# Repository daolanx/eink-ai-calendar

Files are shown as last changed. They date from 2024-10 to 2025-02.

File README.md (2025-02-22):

# Eink-AI-Calendar

English | [中文版](README-zh.md)

This is an ESP32-based E-ink AI Calendar. Like time itself - which cannot hold onto yesterday, makes each day new, and keeps tomorrow unknown - it displays daily images and text that cannot be saved or changed, with a low-power, switch-free design.

## 1. Features

- Displays date, weather, and holiday information
- Shows daily inspirational quotes
- Displays AI-generated images based on weather, holidays, and quotes
- Automatically updates at midnight

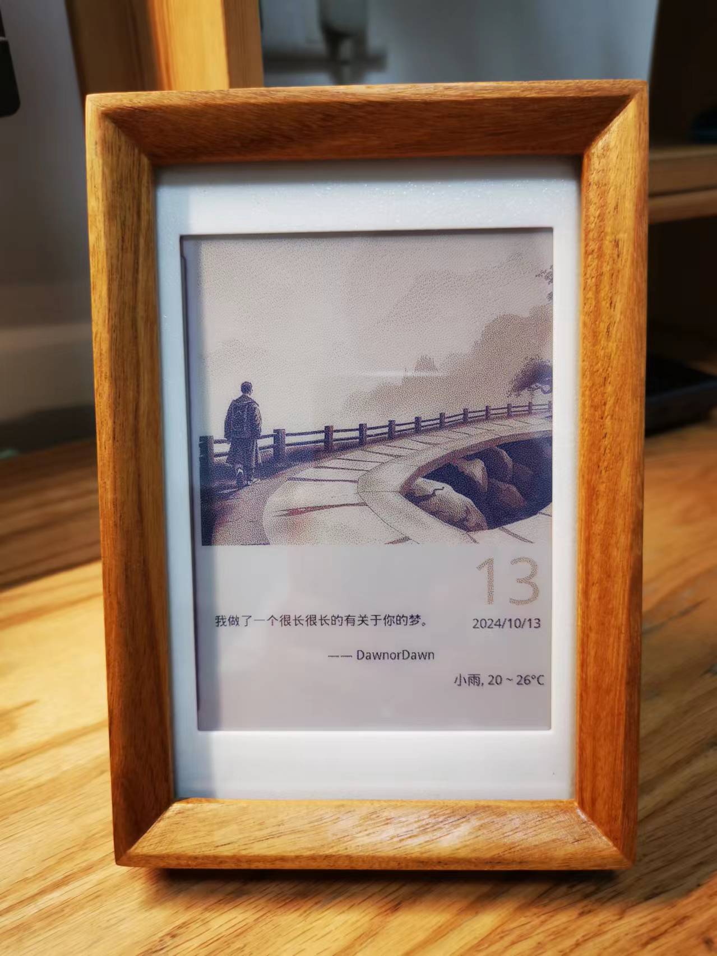
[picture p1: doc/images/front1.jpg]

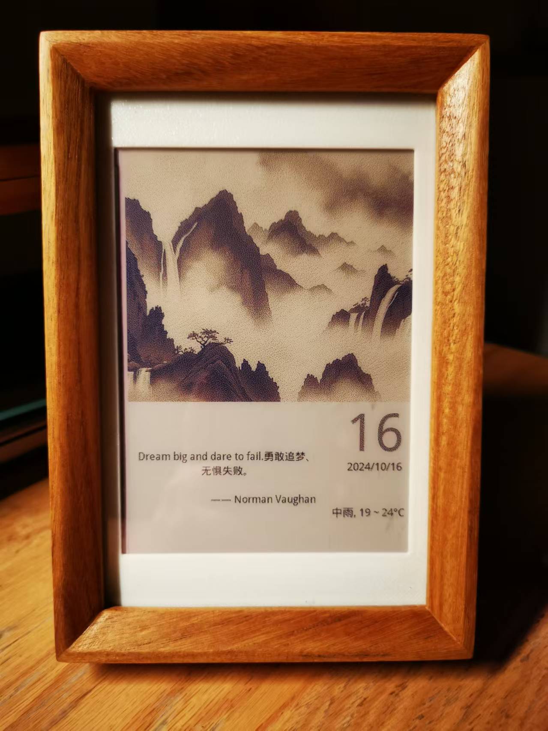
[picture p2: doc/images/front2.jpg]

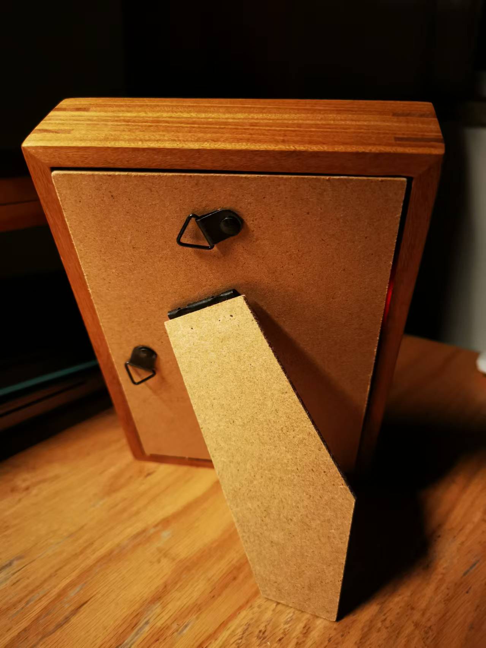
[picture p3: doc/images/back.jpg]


## 2. Hardware & Appearance

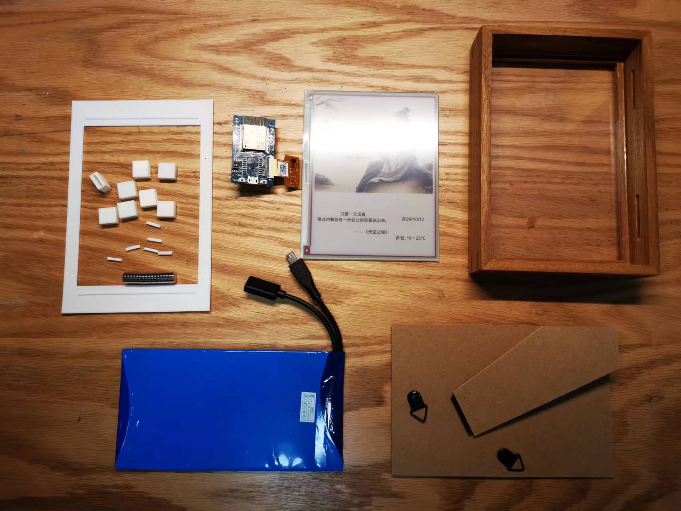
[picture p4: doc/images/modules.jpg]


### 2.1 Hardware

Uses low-power hardware components:

- Screen: Waveshare 5.65-inch 7-color E-ink display [5.65inch e-Paper Module (F)](https://www.waveshare.net/shop/5.65inch-e-Paper-Module-F.htm)
- Driver Board: Waveshare ESP32 module with E-ink display driver [e-Paper-ESP32-Driver-Board](https://www.waveshare.net/shop/e-Paper-ESP32-Driver-Board.htm)
- Battery: ZhongShunXin 5V constant voltage lithium battery 5000mAh (size chosen based on frame interior dimensions), with Type-C female charging port and microUSB male discharge port

### 2.2 Appearance

- Frame: 6-inch (10.2 cm \* 15.2 cm) wooden photo frame from online marketplace, specifically chosen with 3cm thickness to accommodate chips and battery
- Back Panel: Separate 6-inch photo album back panel (original wooden back panel was too thick)
- Frame & Back Panel Connection: Magnetic attachment for easy charging and debugging. Uses 8mm diameter, 2mm thick circular magnets
- 3D Printed Parts: A frame mask to center the screen and cover screen edges; 8 small boxes to house magnets, increasing adhesion area and reducing excessive magnetic force (source files in /3d directory)

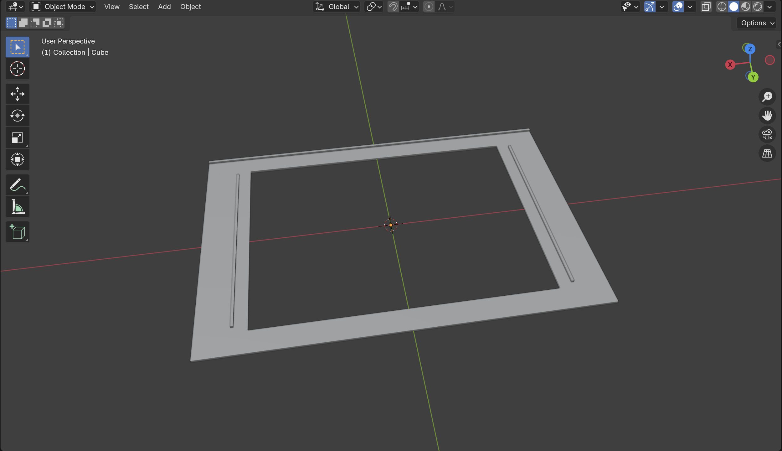
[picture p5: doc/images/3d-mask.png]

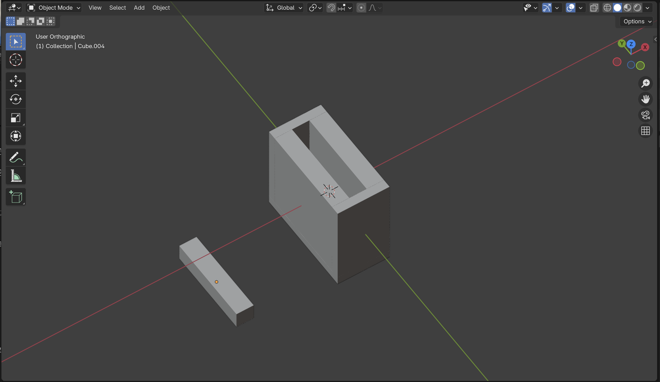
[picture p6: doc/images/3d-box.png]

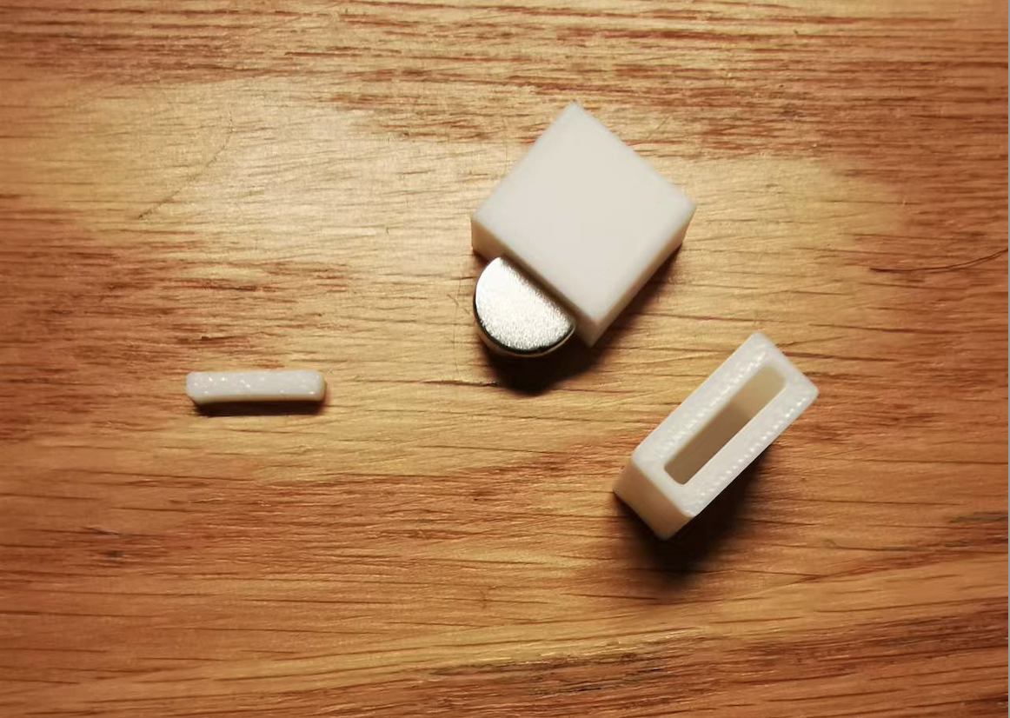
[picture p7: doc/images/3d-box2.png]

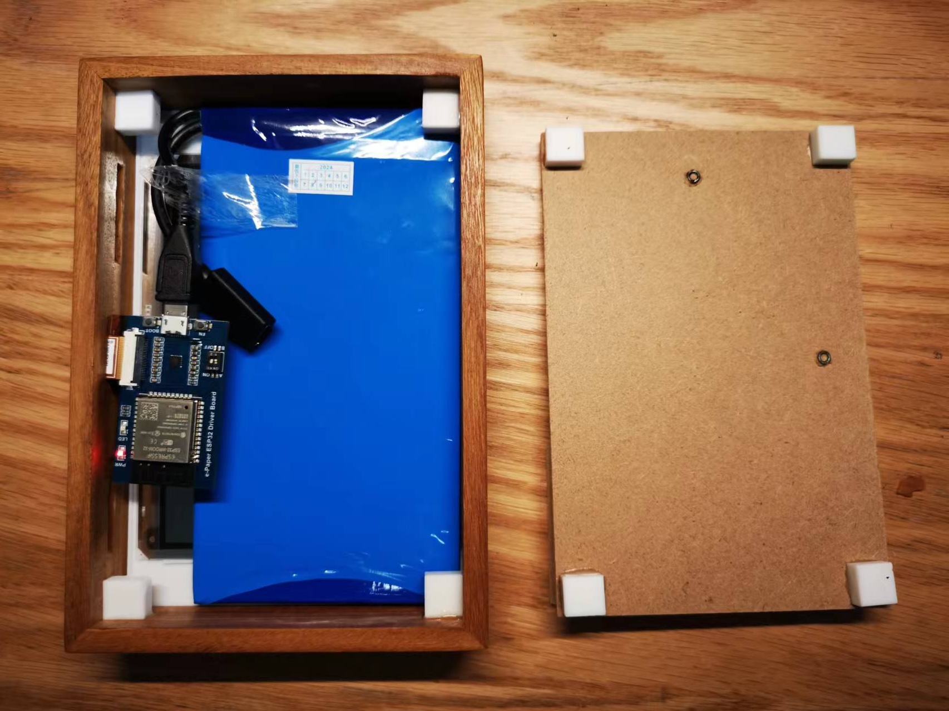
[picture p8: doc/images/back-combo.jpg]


## 3. Software

### 3.1 Architecture

- Client/Server Architecture: Due to ESP32's limited computing power, a C/S architecture is used. ESP32 acts as client, reading processed byte data from HTTP endpoints to display on the E-ink screen, reducing ESP32's workload.

### 3.2 Client

The client handles update detection and image rendering.

- Update Timing:
  - Daily midnight updates: ESP32 wakes hourly, connects to WiFi for time check, updates calendar if midnight
  - Updates on power connection or reset: Updates when esp_reset_reason() returns ESP_RST_POWERON, useful for initialization and debugging
- Rendering Method: Due to limited documentation on partial refresh, full screen refresh is used. All image and data processing happens server-side. Note: Screen refresh interval should be >30s to prevent damage from frequent updates.

### 3.3 Server

The server handles data aggregation and image processing.

- Data Aggregation: Retrieves weather, holiday information, and AI-generated images through APIs
- Image Processing: Converts quote text and holiday information to images, combines with AI images into calendar layout, applies dithering algorithms and data compression

View calendar preview through the /show endpoint.
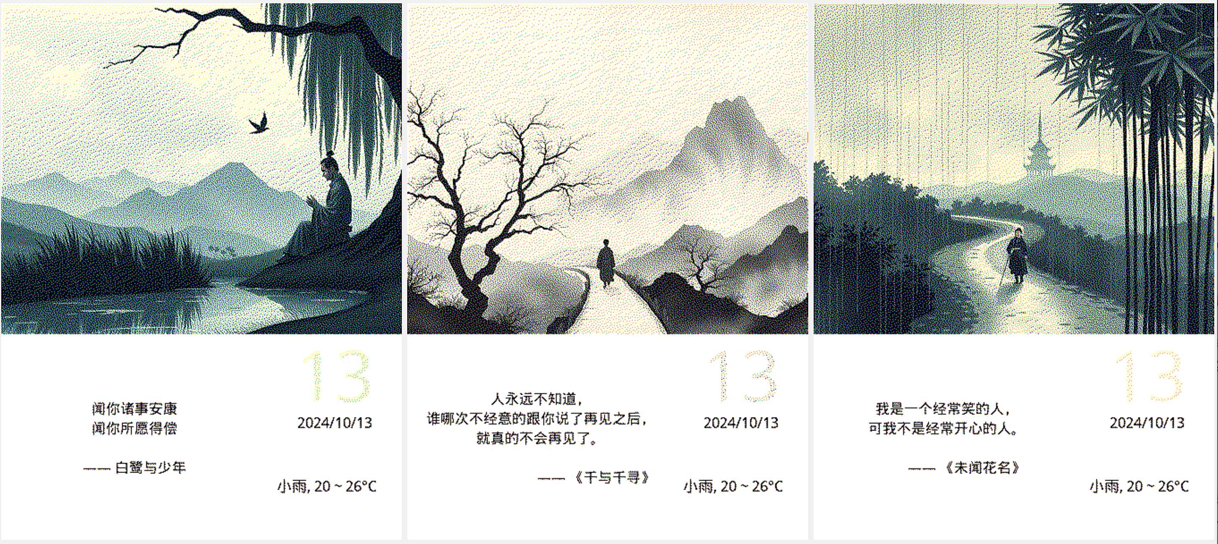
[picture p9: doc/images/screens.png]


ESP32 retrieves data through the /bytes endpoint.

## 4. Setup

### 4.1 Server Deployment

Choose between local Python deployment or Docker.

#### 4.1.1 Local Deployment

- Install Python 3.8 and dependencies
- Rename server/config_demo.py to config.py and fill in weather, AI, and other configuration details
- Run python app.py to start web service. Verify through /show and /bytes endpoints. /show should display calendar image, /bytes should return 134KB image data.

#### 4.1.2 Docker Deployment (Synology Example)

- Debug locally following 4.1.1
- Install [docker](https://docs.docker.com/desktop/install/mac-install/)
- Build image in server directory. For Mac building targeting Synology, use [buildx](https://github.com/docker/buildx) for linux/amd64 architecture:

```bash
docker buildx build --platform linux/amd64 -t eink-calendar-server:amd64 --load .
```

- Export image to tar:

```bash
docker save -o eink-calendar-server.tar eink-calendar-server:amd64
```

- Install Docker package on Synology, import image, create container.

### 4.2 ESP32 Programming

#### 4.2.1 Environment Setup and Verification

- Follow [E-Paper_ESP32_Driver_Board](https://www.waveshare.net/wiki/E-Paper_ESP32_Driver_Board) documentation to install [Arduino IDE and ESP32 drivers](https://www.waveshare.net/wiki/Template:Arduino_ESP32/8266_Offline_Installation)
- Run official demos to verify WiFi and Bluetooth functionality, image display

#### 4.2.2 Calendar Program Upload

Rename esp32/config_demo.h to config.h, fill in WiFi details and server IP/port from previous step, then upload.

## 5. Acknowledgments

- Thanks to LiangGao's [article](https://sspai.com/post/82704) for inspiration and key technical insights on C/S architecture and data compression
- Special thanks to [Debatrix](https://github.com/Debatrix) and their [Eink-Calendar](https://github.com/Debatrix/eInkPhotoAlbum) project, which this project heavily references and simplifies using cursor

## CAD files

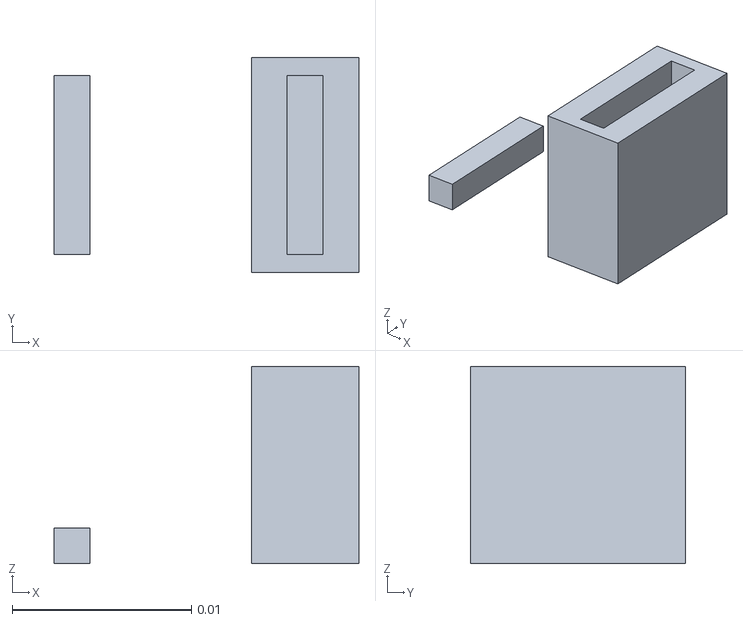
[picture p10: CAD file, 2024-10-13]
3d/magnet-block/magnet-block.stl
0.017 x 0.012 x 0.011

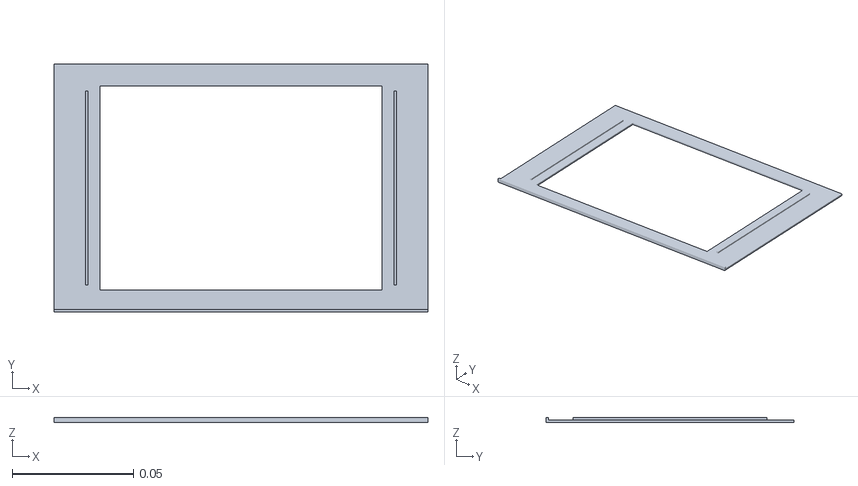
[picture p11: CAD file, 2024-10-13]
3d/mask/mask.stl
0.154 x 0.102 x 0.002

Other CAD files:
3d/magnet-block/magnet-block.blend
3d/mask/mask.blend

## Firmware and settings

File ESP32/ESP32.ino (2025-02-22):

#include <Arduino.h>
#include <WiFi.h>
#include <esp_sleep.h>
#include <HTTPClient.h>
#include <stdlib.h>
#include <string.h>
#include "config.h"
#include "EInk.h"
#include "time.h"

#define MAX_WIFI_CONNECT_RETRY 20  /* Maximum number of WiFi connection retries */
#define US_TO_S_FACTOR 1000000     /* Conversion factor from microseconds to seconds */
#define TIME_TO_SLEEP (60 * 60 * 1) /* Time ESP32 will sleep (in seconds) - 1 hour */

#define NTP_SERVER "pool.ntp.org"   /* NTP server address */
#define GMT_OFFSET_SEC (8 * 3600)   /* GMT offset (in seconds) - UTC+8 */
#define DAYLIGHT_OFFSET_SEC 0       /* Daylight saving time offset (in seconds) */

void setup() {
    Serial.begin(115200);
    delay(1000);  // Give some time for serial to be ready
    Serial.println("ESP32 starting up...");

    if (!connectWiFi()) {
        Serial.println("Failed to connect to WiFi");
        return;
    }

    // Initialize and sync network time
    configTime(GMT_OFFSET_SEC, DAYLIGHT_OFFSET_SEC, NTP_SERVER);
    Serial.println("Waiting for time sync...");
    delay(3000);  // Give some time for time sync

    // Check if it's early morning or if it's a restart
    bool isEarly = isEarlyMorning();
    bool isPowerOn = isRestByPowerOn();
    if (isEarly || isPowerOn) {
        Serial.println("Updating E-Ink display. Reason: " + String(isEarly ? "Early morning" : "Restarted by power on"));
        updateEInk();
    } else {
        Serial.println("Skip E-Ink update. Reason: Not early morning and not restarted by power on");
    }

    // Set timer wakeup
    esp_sleep_enable_timer_wakeup((uint64_t)TIME_TO_SLEEP * US_TO_S_FACTOR);
    Serial.println("Setup ESP32 to sleep for " + String(TIME_TO_SLEEP) + " seconds");
    
    // Enter deep sleep
    Serial.println("Going to deep sleep now");
    esp_deep_sleep_start();
}

void loop() {
    // Loop function won't be executed in deep sleep mode
}

bool connectWiFi() {
    int wifi_connect_try = 0;
    WiFi.begin(ssid, password);
    Serial.println("Connecting to WiFi...");
    while (WiFi.status() != WL_CONNECTED && wifi_connect_try < MAX_WIFI_CONNECT_RETRY) {
        delay(500);
        Serial.print(".");
        wifi_connect_try++;
    }

    if (WiFi.status() == WL_CONNECTED) {
        Serial.print("Connected, IP address: ");
        Serial.println(WiFi.localIP());
        return true;
    } else {
        Serial.println("Failed to connect to WiFi");
        return false;
    }
}

bool isEarlyMorning() {
    struct tm timeinfo;
    if (!getLocalTime(&timeinfo)) {
        Serial.println("Failed to obtain time");
        return false;
    }
    Serial.println(&timeinfo, "%A, %B %d %Y %H:%M:%S");
    Serial.println("Current hour: " + String(timeinfo.tm_hour));
    // Check if it's early morning
    bool isEarlyMorning = timeinfo.tm_hour == 0;
    Serial.println("isEarlyMorning: " + String(isEarlyMorning));
    return isEarlyMorning;
}

bool isRestByPowerOn() {
    esp_reset_reason_t reset_reason = esp_reset_reason();
    Serial.println("Reset reason: " + String(reset_reason));
    return (reset_reason == ESP_RST_POWERON);
}

void updateEInk() {
    String req = String(host) + "/bytes";
    HTTPClient http;
    http.begin(req);
    
    http.setTimeout(60000);
    
    Serial.println("Sending HTTP request to: " + req);
    int httpCode = http.GET();
    Serial.println("HTTP response code: " + String(httpCode));
    
    int len = http.getSize();
    Serial.println("Response size: " + String(len));
    
    if (httpCode == HTTP_CODE_OK && len == IMAGE_SIZE) {
        // ... (rest of the updateEInk function remains the same)
        DEV_Module_Init();
        EPD_5IN65F_Init();
        delay(10);
        EPD_5IN65F_Display_begin();
        uint8_t temp_buff[TEMP_BUFF_SIZE] = {0};
        int offset = 0;
        WiFiClient *stream = http.getStreamPtr();
        stream->setTimeout(60000);
        while (http.connected() && (offset < IMAGE_SIZE)) {
            size_t size = stream->available();
            if (size) {
                int c = stream->readBytes(temp_buff, ((size > sizeof(temp_buff)) ? sizeof(temp_buff) : size));
                for (int i = 0; i < c; i++) {
                    EPD_5IN65F_SendData(temp_buff[i]); // Send received data
                }
                offset += c;
                Serial.println("received: " + String(offset) + "/" + String(IMAGE_SIZE));
                delay(10);
            }
        }
        delay(100);
        EPD_5IN65F_Display_end();
        EPD_5IN65F_Sleep();
        Serial.println("update E-Ink done");
    } else {
        Serial.println("update E-Ink failed. HTTP code: " + String(httpCode) + ", Length: " + String(len));
    }
    http.end();
}

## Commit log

2024-10-13 init: initialize esp32 and server code.
2024-10-13 init(3d): initialization album mask and magnet block.
    [magnet-block.blend, magnet-block.stl, mask.blend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]
2024-10-14 chore(esp32): change esp32 -> ESP32 for fix Arduino IDE compile error.
    [ESP32.ino]
2024-10-16 feat(updateInk): When the power is turned on, it will also perform an update.
2024-10-17 fix(esp32): fix configTime arguments.
    [ESP32.ino]
